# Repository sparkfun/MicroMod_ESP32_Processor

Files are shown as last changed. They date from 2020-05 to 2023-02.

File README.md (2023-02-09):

SparkFun MicroMod ESP32 Processor Board
========================================

SparkFun MicroMod ESP32 Processor Board (https://www.sparkfun.com/products/16781)

[*SparkFun MicroMod ESP32 Processor Board (16781)*](https://www.sparkfun.com/products/16781)

The MicroMod ESP32 Processor Board combines Espressif's ESP32 with our M.2 connector interface to bring a power-packed processor board into our MicroMod ecosystem. 

The ESP32 includes a laundry list of functionality, including the dual-core Tensilica LX6 microprocessor, 240MHz clock frequency, 520kB internal SRAM, integrated WiFi transceiver, and hardware accelerated encryption (AES, SHA2, ECC, RSA-4096). With this MicroMod processor board, you have access to 8 general use IO pins, dedicated analog, digital, and PWM pins, as well as all the fan favorites - SPI, I<sup>2</sup>C, UART, and SDIO. Add to that 16MB flash storage and sleep current of around 500&micro;A, and you've got a perfect storm of versatility. 

Grab yourself a SparkFun MicroMod ESP32 Processor Board and a compatible carrier board and get to hacking! 

Repository Contents
-------------------

* **/Documentation** - Data sheets, additional product information
* **/Hardware** - Eagle design files (.brd, .sch)
* **/Production** - Production panel files (.brd)

Documentation
--------------
* **[Hookup Guide](https://learn.sparkfun.com/tutorials/micromod-esp32-processor-board-hookup-guide)** - Basic hookup guide for the SparkFun MicroMod ESP32 Processor Board.
* **[Getting Started with MicroMod](https://learn.sparkfun.com/tutorials/getting-started-with-micromod)** - A tutorial to help you get started with the MicroMod Ecosystem. 
* **[Designing with MicroMod](https://learn.sparkfun.com/tutorials/designing-with-micromod)** - A tutorial to walk you through the specs of the MicroMod processor and carrier board as well as the basics of incorporating the MicroMod form factor into your own PCB designs.

License Information
-------------------

This product is _**open source**_! 

Please review the LICENSE.md file for license information. 

If you have any questions or concerns on licensing, please contact technical support on our [SparkFun forums](https://forum.sparkfun.com/viewforum.php?f=152).

Distributed as-is; no warranty is given.

- Your friends at SparkFun.

_<COLLABORATION CREDIT>_

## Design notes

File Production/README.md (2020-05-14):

SparkFun <PRODUCT NAME> Production Files
=========================================

These are the production files SparkFun uses for printing PCBs.

License Information
-------------------
This product is open source! 

The hardware is released under [Creative Commons ShareAlike 4.0 International](https://creativecommons.org/licenses/by-sa/4.0/).

Please use, reuse, and modify these files as you see fit. Please maintain attribution to SparkFun Electronics and release anything derivative under the same license.

Distributed as-is; no warranty is given.

- Your friends at SparkFun.

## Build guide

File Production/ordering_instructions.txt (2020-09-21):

panel size, 194x70mm
PCB thickness, 0.8mm
number of layers, 4
soldermask color, Red
silkscreen color, White
oz copper, 1oz
finish, ENIG
stencils, top+bottom
pcs per panel, 16
min trace width, 0.1270mm / 0.0050in
min drill size, 0.2000mm / 0.0079in
filename to layer stackup 1/2/3/4: GTL, GL2, GL3, GBL

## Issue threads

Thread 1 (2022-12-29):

ESP32 automatic reset into bootloader fails due to missing capacitor on RESET (EN) signal

cdwilson, 2022-12-29:
### Issue
I get an error message like the following when trying to program the MicroMod ESP32 Processor board with `esptool.py` using the automatic reset hardware built onto the board:

```
esptool.py v3.3
Serial port /dev/cu.usbserial-2130
Connecting......................................

A fatal error occurred: Failed to connect to Espressif device: Wrong boot mode detected (0x13)! The chip needs to be in download mode.
For troubleshooting steps visit: https://docs.espressif.com/projects/esptool/en/latest/troubleshooting.html
```

### Solution

I think the board is missing a capacitor between the `RESET#` signal (connected to ESP32 `CHIP_PU`/`EN`) and `GND`. This capacitor is required for the automatic reset circuit to work reliably.

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

See https://docs.espressif.com/projects/esptool/en/latest/esp32/advanced-topics/boot-mode-selection.html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, specifically:

> adding a capacitor between the EN pin and GND (in the 1uF-10uF range) is necessary for the reset circuitry to work reliably

### Rework

Here's some photos of the rework I did to get things working in case somebody comes across this issue in the future.

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

After adding a 1 uF capacitor between the `RESET#` signal and `GND`, programming via `esptool.py` works correctly:

```
esptool.py v3.3
Serial port /dev/cu.usbserial-2130
Connecting....
Detecting chip type... Unsupported detection protocol, switching and trying again...
Connecting....
Detecting chip type... ESP32
Chip is ESP32-D0WDQ6-V3 (revision 3)
Features: WiFi, BT, Dual Core, 240MHz, VRef calibration in efuse, Coding Scheme None
Crystal is 40MHz
MAC: 24:6f:28:8f:5d:bc
Uploading stub...
Running stub...
Stub running...
Changing baud rate to 921600
Changed.
Configuring flash size...
Auto-detected Flash size: 16MB
Flash will be erased from 0x00001000 to 0x00007fff...
Flash will be erased from 0x00008000 to 0x00008fff...
Flash will be erased from 0x00010000 to 0x00033fff...
Flash params set to 0x0240
Wrote 32768 bytes at 0x00001000 in 0.5 seconds (531.7 kbit/s)...
Hash of data verified.
Wrote 16384 bytes at 0x00008000 in 0.2 seconds (582.0 kbit/s)...
Hash of data verified.
Wrote 147456 bytes at 0x00010000 in 2.0 seconds (595.1 kbit/s)...
Hash of data verified.

Leaving...
Hard resetting via RTS pin...
```

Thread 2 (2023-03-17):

Hardware revision request: Improve power efficiency

adamgarbo, 2023-03-17:
Hi folks,

Unfortunately, the ESP32 MicroMod Process cannot achieve low quiescent draw when in deep sleep. I figured I'd throw this up on GitHub just in case the ESP32 ever sees a hardware revision.

Quoting @chEEm from the forums: https://forum.sparkfun.com/viewtopic.php?f=182&t=58183

> Unfortunately the CP210X USB to serial chip on the ESP32 module is connected to the 3.3V rail and not bus powered from 5V. The suspend pin is not utilized either which could reduce the quiescent current but is rather useless since the chip only needs to be active with a USB connection. A few traces need to be cut along with some jumper wires added to remove the VREGIN pin from 3.3V and add to V_USB power. It was relatively straight forward to do with a microscope and some 32 AWG wire. The bus powered configuration is shown in the typical connection diagram on page 18 of the CP210X datasheet ([https://www.silabs.com/documents/public ... 2102-9.pdf](https://www.silabs.com/documents/public/data-sheets/CP2102-9.pdf)). Afterwards my deep sleep 3.3V current dropped from 3mA to under 10uA.

At the very least, the product page should remove the stated 500 uA hibernation draw.

Cheers,
Adam

Closed 2024-09-25.

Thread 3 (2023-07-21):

Bootstrap pins on MicroMod connector can cause incompatibilities

shulltronics, 2023-07-21:
Hi there,

I'm one of the SPE design challenge participants, so I received a Single Pair Ethernet kit that includes this board. When I started to play with this kit, I realized that I couldn't flash the Esp32! This was my first time working with one, so I subsequently learned about the bootstrap pins, and then realized that GPIO12 on the Esp32 (broken out to PWM1 (pin 47?) on the MircoMod connector) was being pulled high by the SPE function board. See [my issue over there](https://github.com/sparkfun/SparkFun_MicroMod_Single_Pair_Ethernet_Function_Board_ADIN1110/issues/1) as well.

#### Work Around
I was able to burn the efuses on the Esp32 with `espefuse.py set_flash_voltage 3.3V` to hard-code the MCU's internal flash to 3.3V.

#### Possible Solutions
While the work around seems to allow the boards to work together, it doesn't seem like the ideal solution, as it requires some specialized knowledge to get to that solution, and is an irreversible action. The only way I could see this being feasible is if Sparkfun did the fuse setting before shipping these boards to customers. The most robust solution, though maybe too limiting, is to remove the bootstrap pins from the MicroMod connector entirely. This would prevent any incompatibilities with future function boards.

Anyway, I would love to hear your thoughts on this! :) Thanks!

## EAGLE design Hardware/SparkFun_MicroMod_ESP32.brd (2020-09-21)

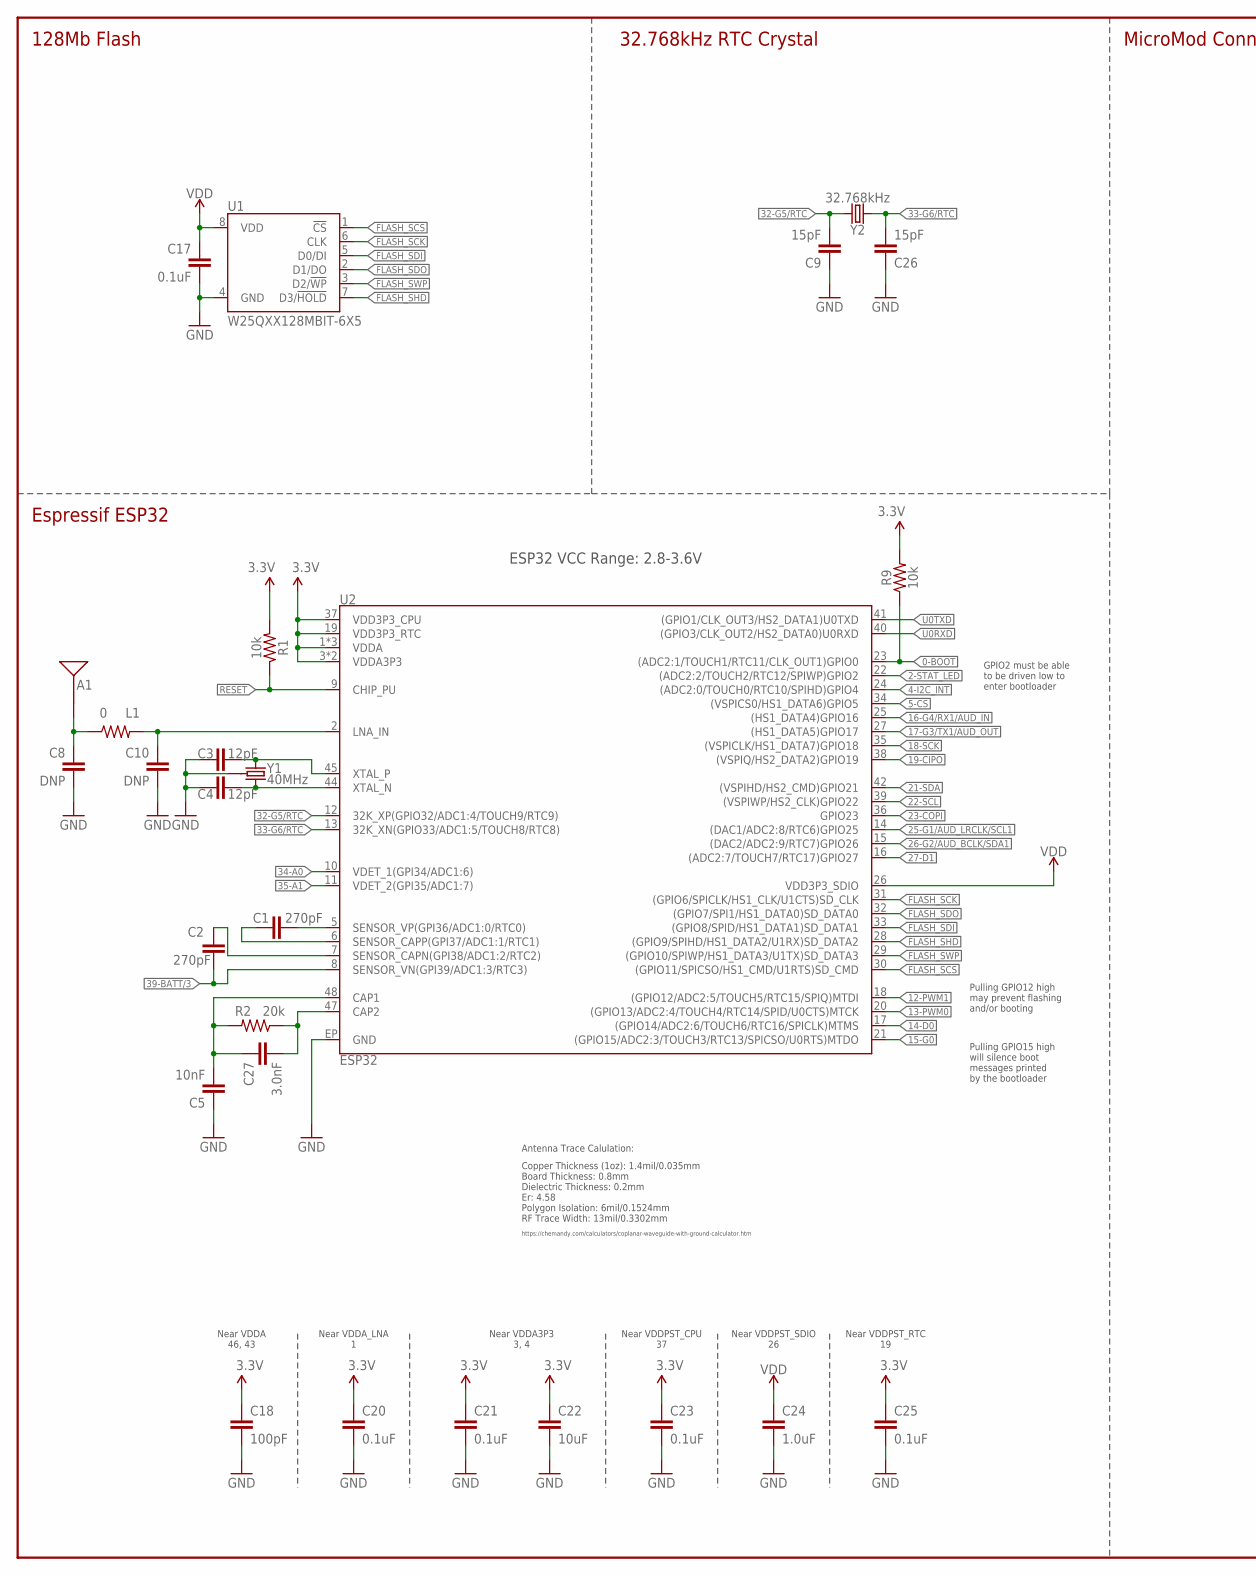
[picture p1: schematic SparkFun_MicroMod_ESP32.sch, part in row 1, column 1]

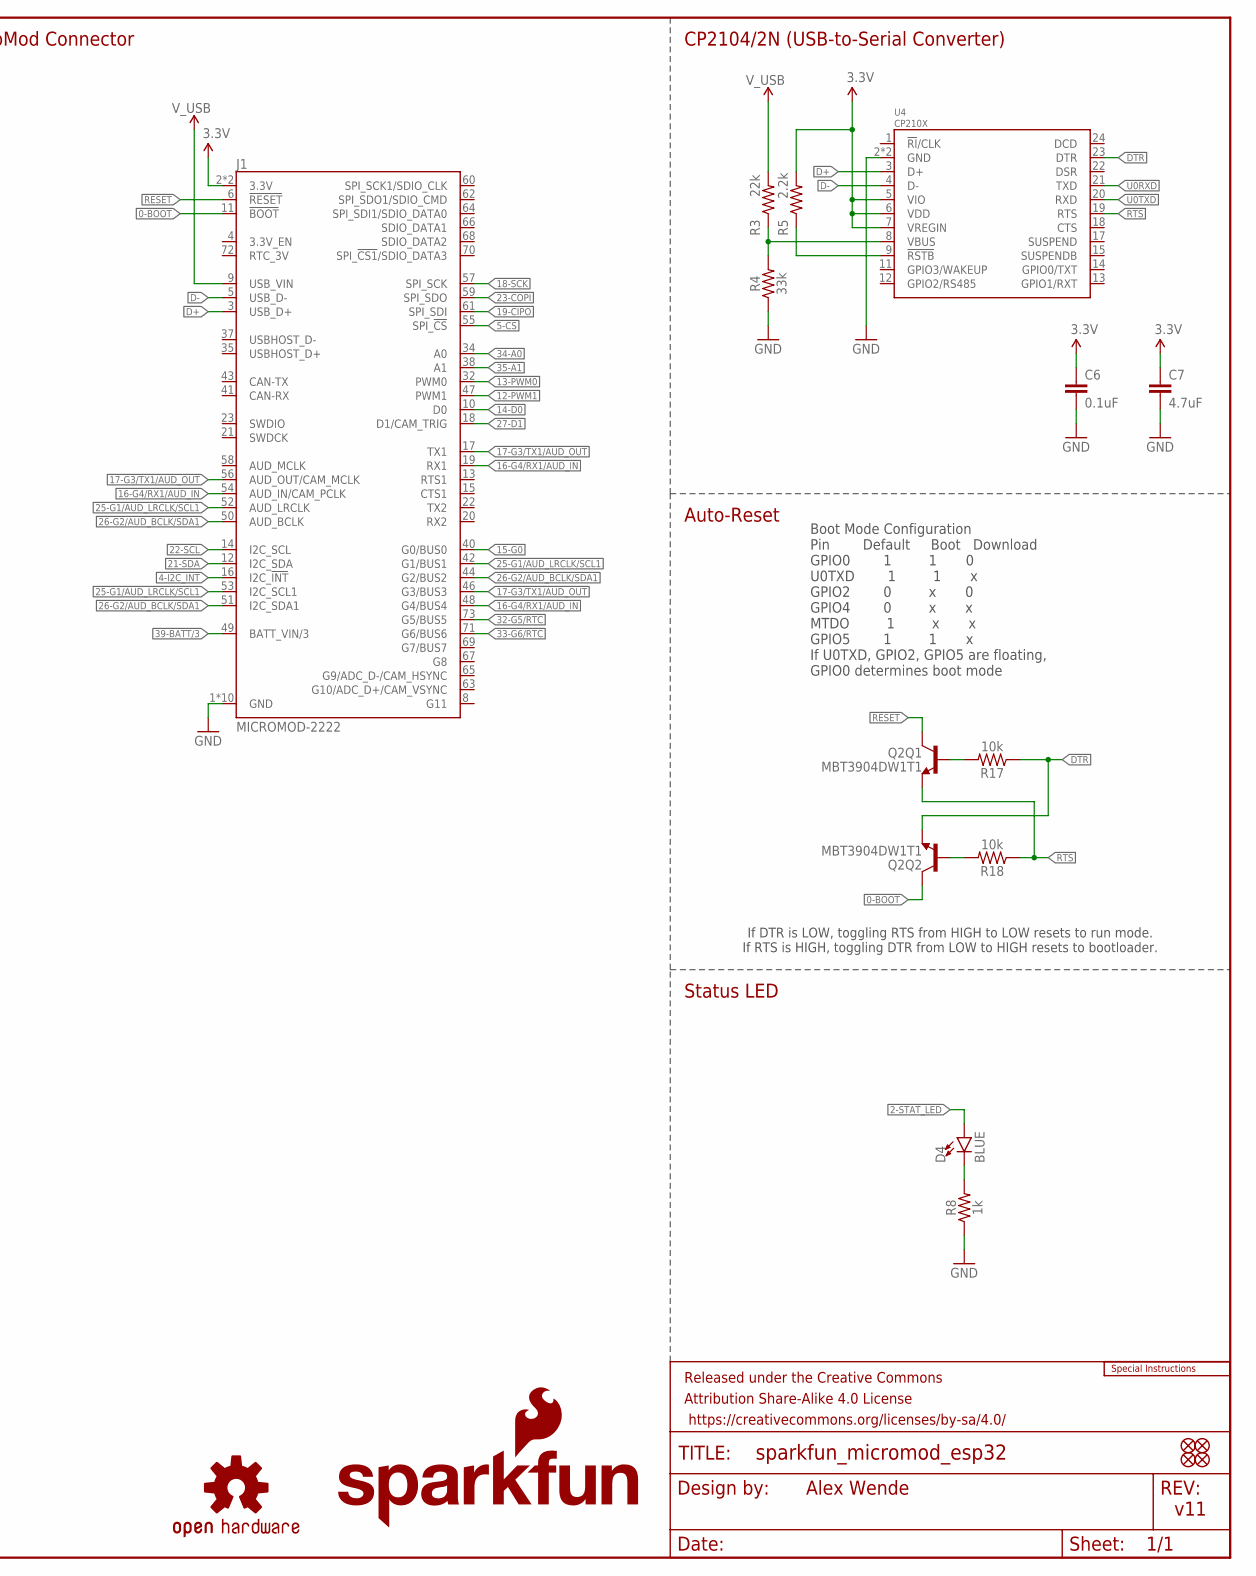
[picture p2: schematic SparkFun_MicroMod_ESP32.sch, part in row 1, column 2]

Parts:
A1: ANTENNA2.4GHZ-8.0X1.0MM; ANT-2.4GHZ-8.0X1.0MM
C1, C2: 270pF; 0402-TIGHT
C3, C4: 12pF; 0402-TIGHT
C5: 10nF; 0402-TIGHT
C6, C17, C20, C21, C23, C25: 0.1uF; 0402-TIGHT
C7: 4.7uF; 0402-TIGHT
C8, C10: DNP; 0402-TIGHT
C9, C26: 15pF; 0402-TIGHT
C18: 100pF; 0402-TIGHT
C22: 10uF; 0402-TIGHT
C24: 1.0uF; 0402-TIGHT
C27: 3.0nF; 0402-TIGHT
D4: BLUE; LED-0603
FD1, FD2, FD3, FD4: FIDUCIALUFIDUCIAL; FIDUCIAL-MICRO
FRAME1: FRAME-LEDGER; CREATIVE_COMMONS
J1: MICROMOD-2222; M.2-CARD-E-22
L1: 0; 0402-TIGHT
LOGO1: SPECIAL_INSTRUCTIONS-ORDERING; ORDERING_INSTRUCTIONS
LOGO2: SFE_LOGO_NAME_FLAME.1_INCH; SFE_LOGO_NAME_FLAME_.1
LOGO3: OSHW-LOGOS; OSHW-LOGO-S
Q2: MBT3904DW1T1; SC70-6
R1, R9, R17, R18: 10k; 0402-TIGHT
R2: 20k; 0402-TIGHT
R3: 22k; 0402-TIGHT
R4: 33k; 0402-TIGHT
R5: 2.2k; 0402-TIGHT
R8: 1k; 0402-TIGHT
U1: W25QXX128MBIT-6X5; WSON-8-6X5
U2: ESP32; QFN48-0.4MM
U4: CP210X; QFN24
Y1: 40MHz; CRYSTAL-SMD-2X2.5MM
Y2: 32.768kHz; CRYSTAL-SMD-3.2X1.5MM

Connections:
0-!BOOT!: J1.11 (!BOOT!), Q2.6 (C), R9.1, U2.23 ((ADC2:1/TOUCH1/RTC11/CLK_OUT1)GPIO0)
2-STAT_LED: D4.A, U2.22 ((ADC2:2/TOUCH2/RTC12/SPIWP)GPIO2)
3.3V: C6.1, C7.1, C18.1, C20.1, C21.1, C22.1, C23.1, C25.1, J1.2 (3.3V), J1.74 (3.3V), R1.2, R5.2, R9.2, U2.1 (VDDA), U2.3 (VDDA3P3), U2.4 (VDDA3P3), U2.19 (VDD3P3_RTC), U2.37 (VDD3P3_CPU), U2.43 (VDDA), U2.46 (VDDA), U4.5 (VIO), U4.6 (VDD), U4.7 (VREGIN)
4-I2C_!INT: J1.16 (I2C_!INT!), U2.24 ((ADC2:0/TOUCH0/RTC10/SPIHD)GPIO4)
5-!CS: J1.55 (SPI_!CS!), U2.34 ((VSPICS0/HS1_DATA6)GPIO5)
12-PWM1: J1.47 (PWM1), U2.18 ((GPIO12/ADC2:5/TOUCH5/RTC15/SPIQ)MTDI)
13-PWM0: J1.32 (PWM0), U2.20 ((GPIO13/ADC2:4/TOUCH4/RTC14/SPID/U0CTS)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)
14-D0: J1.10 (D0), U2.17 ((GPIO14/ADC2:6/TOUCH6/RTC16/SPICLK)MTMS)
15-G0: J1.40 (G0/BUS0), U2.21 ((GPIO15/ADC2:3/TOUCH3/RTC13/SPICSO/U0RT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)
16-G4/RX1/AUD_IN: J1.19 (RX1), J1.48 (G4/BUS4), J1.54 (AUD_IN/CAM_PCLK), U2.25 ((HS1_DATA4)GPIO16)
17-G3/TX1/AUD_OUT: J1.17 (TX1), J1.46 (G3/BUS3), J1.56 (AUD_OUT/CAM_MCLK), U2.27 ((HS1_DATA5)GPIO17)
18-SCK: J1.57 (SPI_SCK), U2.35 ((VSPICLK/HS1_DATA7)GPIO18)
19-CIPO: J1.61 (SPI_SDI), U2.38 ((VSPIQ/HS2_DATA2)GPIO19)
21-SDA: J1.12 (I2C_SDA), U2.42 ((VSPIHD/HS2_CMD)GPIO21)
22-SCL: J1.14 (I2C_SCL), U2.39 ((VSPIWP/HS2_CLK)GPIO22)
23-COPI: J1.59 (SPI_SDO), U2.36 (GPIO23)
25-G1/AUD_LRCLK/SCL1: J1.42 (G1/BUS1), J1.52 (AUD_LRCLK), J1.53 (I2C_SCL1), U2.14 ((DAC1/ADC2:8/RTC6)GPIO25)
26-G2/AUD_BCLK/SDA1: J1.44 (G2/BUS2), J1.50 (AUD_BCLK), J1.51 (I2C_SDA1), U2.15 ((DAC2/ADC2:9/RTC7)GPIO26)
27-D1: J1.18 (D1/CAM_TRIG), U2.16 ((ADC2:7/TOUCH7/RTC17)GPIO27)
32-G5/RTC: C9.2, J1.73 (G5/BUS5), U2.12 (32K_XP(GPIO32/ADC1:4/TOUCH9/RTC9)), Y2.P$1 (1)
33-G6/RTC: C26.2, J1.71 (G6/BUS6), U2.13 (32K_XN(GPIO33/ADC1:5/TOUCH8/RTC8)), Y2.P$2 (2)
34-A0: J1.34 (A0), U2.10 (VDET_1(GPI34/ADC1:6))
35-A1: J1.38 (A1), U2.11 (VDET_2(GPI35/ADC1:7))
36: C1.2, U2.5 (SENSOR_VP(GPI36/ADC1:0/RTC0))
37: C1.1, U2.6 (SENSOR_CAPP(GPI37/ADC1:1/RTC1))
38: C2.1, U2.7 (SENSOR_CAPN(GPI38/ADC1:2/RTC2))
39-BATT/3: C2.2, J1.49 (BATT_VIN/3), U2.8 (SENSOR_VN(GPI39/ADC1:3/RTC3))
!RESET: J1.6 (!RESET!), Q2.3 (C), R1.1, U2.9 (CHIP_PU)
CAP_10N: C5.2, C27.1, R2.2, U2.48 (CAP1)
D+: J1.3 (USB_D+), U4.3 (D+)
D-: J1.5 (USB_D-), U4.4 (D-)
DTR: Q2.1 (E), R17.1, U4.23 (DTR)
FLASH_SCK: U1.6 (CLK), U2.31 ((GPIO6/SPICLK/HS1_CLK/U1CTS)SD_CLK)
FLASH_SCS: U1.1 (!CS!), U2.30 ((GPIO11/SPICSO/HS1_CMD/U1RTS)SD_CMD)
FLASH_SDI: U1.5 (D0/DI), U2.33 ((GPIO8/SPID/HS1_DATA1)SD_DATA1)
FLASH_SDO: U1.2 (D1/DO), U2.32 ((GPIO7/SPI1/HS1_DATA0)SD_DATA0)
FLASH_SHD: U1.7 (D3/!HOLD!), U2.28 ((GPIO9/SPIHD/HS1_DATA2/U1RX)SD_DATA2)
FLASH_SWP: U1.3 (D2/!WP!), U2.29 ((GPIO10/SPIWP/HS1_DATA3/U1TX)SD_DATA3)
GND: C3.1, C4.1, C5.1, C6.2, C7.2, C8.2, C9.1, C10.2, C17.2, C18.2, C20.2, C21.2, C22.2, C23.2, C24.2, C25.2, C26.1, J1.1 (GND), J1.7 (GND), J1.33 (GND), J1.36 (GND), J1.39 (GND), J1.45 (GND), J1.75 (GND), J1.GND1 (GND), J1.GND2 (GND), J1.GND3 (GND), R4.1, R8.1, U1.4 (GND), U2.EP (GND), U4.2 (GND), U4.PAD (GND), Y1.P2 (GND), Y1.P4 (GND)
unnamed: D4.C, R8.2
unnamed: R3.1, R4.2, U4.8 (VBUS)
unnamed: R5.1, U4.9 (!RSTB)
unnamed: C27.2, R2.1, U2.47 (CAP2)
unnamed: A1.FEED, C8.1, L1.1
unnamed: C10.1, L1.2, U2.2 (LNA_IN)
unnamed: Q2.5 (B), R17.2
unnamed: Q2.2 (B), R18.2
unnamed: C3.2, U2.45 (XTAL_P), Y1.P1 (1)
unnamed: C4.2, U2.44 (XTAL_N), Y1.P3 (2)
RTS: Q2.4 (E), R18.1, U4.19 (RTS)
U0RXD: U2.40 ((GPIO3/CLK_OUT2/HS2_DATA0)U0RXD), U4.21 (TXD)
U0TXD: U2.41 ((GPIO1/CLK_OUT3/HS2_DATA1)U0TXD), U4.20 (RXD)
VDD: C17.1, C24.1, U1.8 (VDD), U2.26 (VDD3P3_SDIO)
V_USB: J1.9 (USB_VIN), R3.2

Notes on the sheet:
Boot Mode Configuration Pin Default Boot Download GPIO0 1 1 0 U0TXD 1 1 x GPIO2 0 x 0 GPIO4 0 x x MTDO 1 x x GPIO5 1 1 x If U0TXD, GPIO2, GPIO5 are floating, GPIO0 determines boot mode
Auto-Reset
Near VDDA 46, 43
Near VDDA_LNA 1
Near VDDA3P3 3, 4
Near VDDPST_CPU 37
Near VDDPST_SDIO 26
Near VDDPST_RTC 19
Espressif ESP32
128Mb Flash
32.768kHz RTC Crystal
Status LED
v11
Alex Wende
ESP32 VCC Range: 2.8-3.6V
If DTR is LOW, toggling RTS from HIGH to LOW resets to run mode. If RTS is HIGH, toggling DTR from LOW to HIGH resets to bootloader.
CP2104/2N (USB-to-Serial Converter)
MicroMod Connector
Antenna Trace Calulation:
Copper Thickness (1oz): 1.4mil/0.035mm Board Thickness: 0.8mm Dielectric Thickness: 0.2mm Er: 4.58 Polygon Isolation: 6mil/0.1524mm RF Trace Width: 13mil/0.3302mm
https://chemandy.com/calculators/coplanar-waveguide-with-ground-calculator.htm
GPIO2 must be able to be driven low to enter bootloader
Pulling GPIO12 high may prevent flashing and/or booting
Pulling GPIO15 high will silence boot messages printed by the bootloader

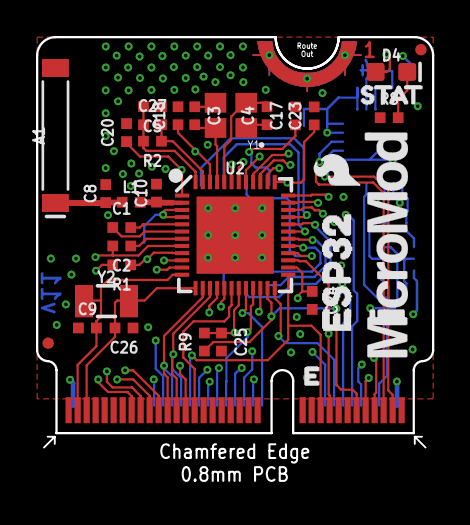
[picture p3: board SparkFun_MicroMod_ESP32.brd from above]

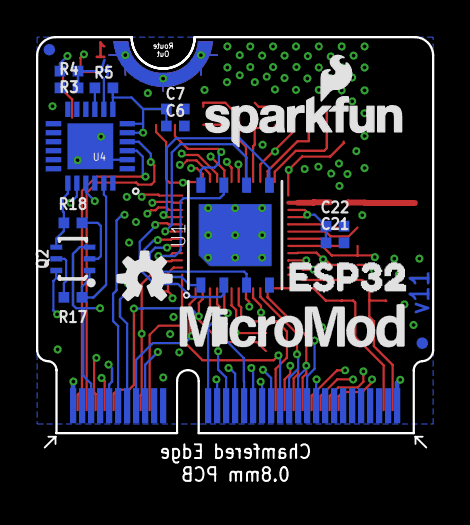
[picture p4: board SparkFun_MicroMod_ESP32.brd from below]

Board: 4 copper layers, 22.0 x 22.8 mm, 53 parts (18 on the bottom side), 54 nets.

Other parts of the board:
U$1: STAT0
U$2, U$6: MICROMOD_LOGO_.5
U$3, U$7: ESP321
U$4: SFE_LOGO_FLAME_.1

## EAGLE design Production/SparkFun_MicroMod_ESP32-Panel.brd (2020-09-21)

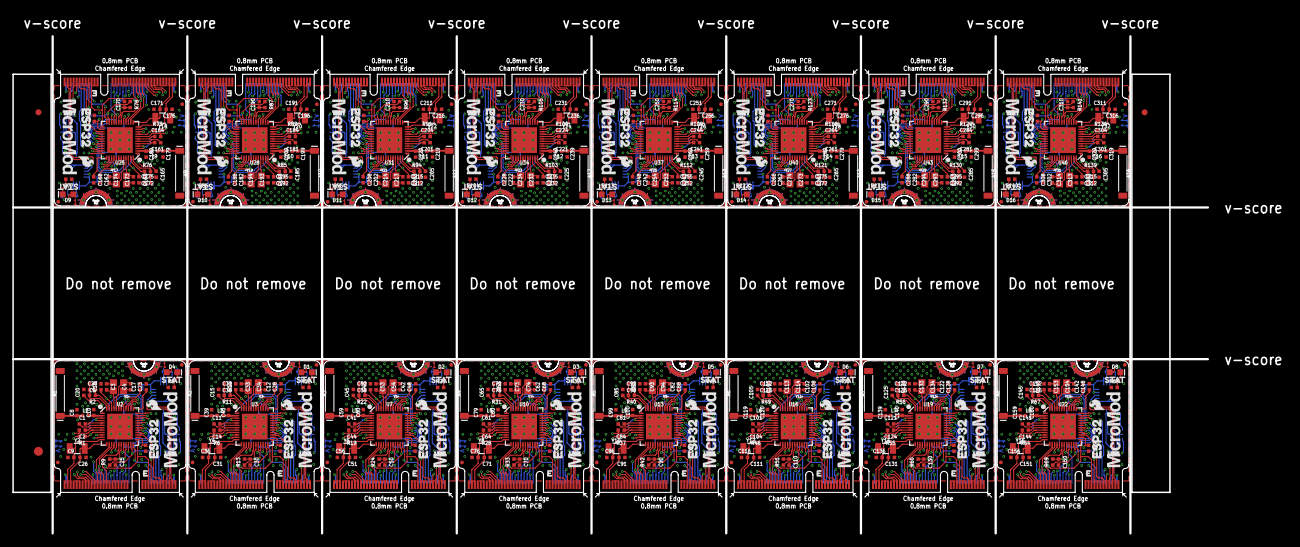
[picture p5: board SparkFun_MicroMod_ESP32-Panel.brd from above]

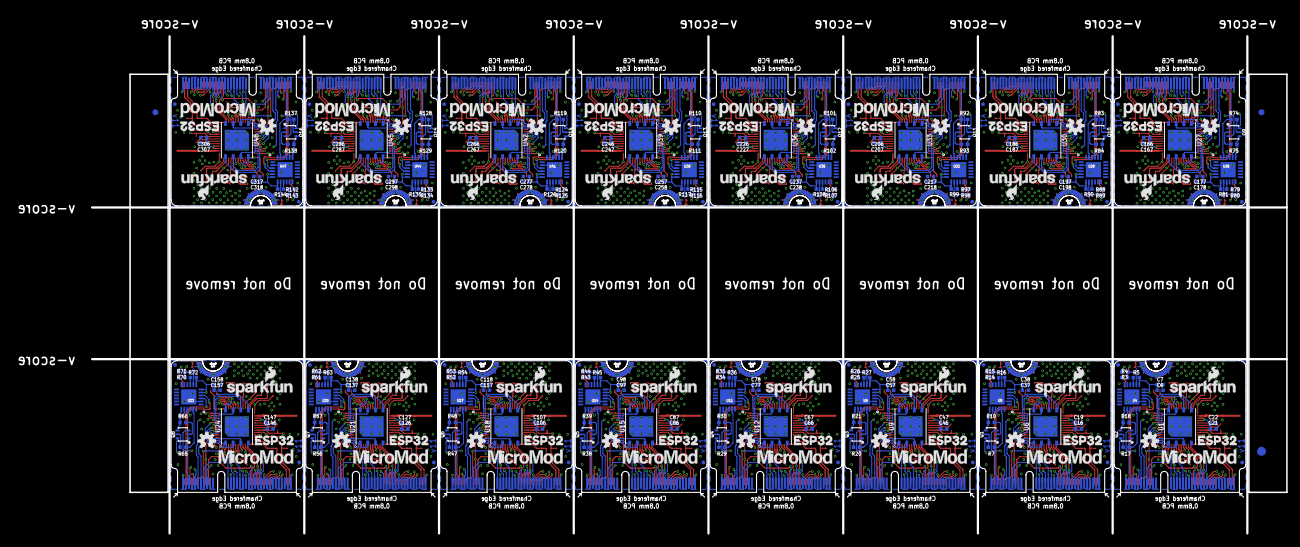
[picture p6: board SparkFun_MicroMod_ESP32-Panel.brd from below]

Board: 4 copper layers, 199.6 x 83.1 mm, 822 parts (291 on the bottom side), 864 nets.

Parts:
A1, A2, A3, A4, A5, A6, A7, A8, A9, A10, A11, A12, A13, A14, A15, A16: ANT-2.4GHZ-8.0X1.0MM
C1, C2, C11, C14, C41, C44, C61, C64, C81, C84, C101, C104, C121, C124, C141, C144, C161, C164, C181, C184, C201, C204, C221, C224, C241, C244, C261, C264, C281, C284, C301, C304: 270pF; 0402-TIGHT
C3, C4, C33, C34, C53, C54, C73, C74, C93, C94, C113, C114, C133, C134, C153, C154, C173, C174, C193, C194, C213, C214, C233, C234, C253, C254, C273, C274, C293, C294, C313, C314: 12pF; 0402-TIGHT
C5, C35, C55, C75, C95, C115, C135, C155, C175, C195, C215, C235, C255, C275, C295, C315: 10nF; 0402-TIGHT
C6, C12, C15, C16, C17, C20, C21, C23, C25, C28, C30, C37, C42, C45, C46, C48, C50, C57, C62, C65, C66, C68, C70, C77, C82, C85, C86, C88, C90, C97, C102, C105, C106, C108, C110, C117, C122, C125, C126, C128, C130, C137, C142, C145, C146, C148, C150, C157, C162, C165, C166, C168, C170, C177, C182, C185, C186, C188, C190, C197, C202, C205, C206, C208, C210, C217, C222, C225, C226, C228, C230, C237, C242, C245, C246, C248, C250, C257, C262, C265, C266, C268, C270, C277, C282, C285, C286, C288, C290, C297, C302, C305, C306, C308, C310, C317: 0.1uF; 0402-TIGHT
C7, C38, C58, C78, C98, C118, C138, C158, C178, C198, C218, C238, C258, C278, C298, C318: 4.7uF; 0402-TIGHT
C8, C10, C39, C40, C59, C60, C79, C80, C99, C100, C119, C120, C139, C140, C159, C160, C179, C180, C199, C200, C219, C220, C239, C240, C259, C260, C279, C280, C299, C300, C319, C320: DNP; 0402-TIGHT
C9, C26, C31, C36, C51, C56, C71, C76, C91, C96, C111, C116, C131, C136, C151, C156, C171, C176, C191, C196, C211, C216, C231, C236, C251, C256, C271, C276, C291, C296, C311, C316: 15pF; 0402-TIGHT
C13, C18, C43, C63, C83, C103, C123, C143, C163, C183, C203, C223, C243, C263, C283, C303: 100pF; 0402-TIGHT
C19, C22, C47, C67, C87, C107, C127, C147, C167, C187, C207, C227, C247, C267, C287, C307: 10uF; 0402-TIGHT
C24, C29, C49, C69, C89, C109, C129, C149, C169, C189, C209, C229, C249, C269, C289, C309: 1.0uF; 0402-TIGHT
C27, C32, C52, C72, C92, C112, C132, C152, C172, C192, C212, C232, C252, C272, C292, C312: 3.0nF; 0402-TIGHT
D1, D2, D3, D4, D5, D6, D7, D8, D9, D10, D11, D12, D13, D14, D15, D16: BLUE; LED-0603
E$1, E$2, E$3, E$4: FIDUCIAL-1X2
E$5, E$6: FIDUCIAL-1.5X3
FD1, FD2, FD3, FD4, FD5, FD6, FD7, FD8, FD9, FD10, FD11, FD12, FD13, FD14, FD15, FD16, FD17, FD18, FD19, FD20, FD21, FD22, FD23, FD24, FD25, FD26, FD27, FD28, FD29, FD30, FD31, FD32, FD33, FD34, FD35, FD36, FD37, FD38, FD39, FD40, FD41, FD42, FD43, FD44, FD45, FD46, FD47, FD48, FD49, FD50, FD51, FD52, FD53, FD54, FD55, FD56, FD57, FD58, FD59, FD60, FD61, FD62, FD63, FD64: FIDUCIALUFIDUCIAL; FIDUCIAL-MICRO
J1, J2, J3, J4, J5, J6, J7, J8, J9, J10, J11, J12, J13, J14, J15, J16: MICROMOD-2222; M.2-CARD-E-22
L1, L2, L3, L4, L5, L6, L7, L8, L9, L10, L11, L12, L13, L14, L15, L16: 0; 0402-TIGHT
LOGO1, LOGO2, LOGO5, LOGO7, LOGO9, LOGO11, LOGO13, LOGO15, LOGO17, LOGO19, LOGO21, LOGO23, LOGO25, LOGO27, LOGO29, LOGO31: SFE_LOGO_NAME_FLAME.1_INCH; SFE_LOGO_NAME_FLAME_.1
LOGO3, LOGO4, LOGO6, LOGO8, LOGO10, LOGO12, LOGO14, LOGO16, LOGO18, LOGO20, LOGO22, LOGO24, LOGO26, LOGO28, LOGO30, LOGO32: OSHW-LOGOS; OSHW-LOGO-S
Q1, Q2, Q3, Q4, Q5, Q6, Q7, Q8, Q9, Q10, Q11, Q12, Q13, Q14, Q15, Q16: MBT3904DW1T1; SC70-6
R1, R6, R7, R9, R10, R13, R17, R18, R19, R20, R21, R24, R28, R29, R30, R33, R37, R38, R39, R42, R46, R47, R48, R51, R55, R56, R57, R60, R64, R65, R66, R69, R73, R74, R75, R78, R82, R83, R84, R87, R91, R92, R93, R96, R100, R101, R102, R105, R109, R110, R111, R114, R118, R119, R120, R123, R127, R128, R129, R132, R136, R137, R138, R141: 10k; 0402-TIGHT
R2, R11, R22, R31, R40, R49, R58, R67, R76, R85, R94, R103, R112, R121, R130, R139: 20k; 0402-TIGHT
R3, R14, R25, R34, R43, R52, R61, R70, R79, R88, R97, R106, R115, R124, R133, R142: 22k; 0402-TIGHT
R4, R15, R26, R35, R44, R53, R62, R71, R80, R89, R98, R107, R116, R125, R134, R143: 33k; 0402-TIGHT
R5, R16, R27, R36, R45, R54, R63, R72, R81, R90, R99, R108, R117, R126, R135, R144: 2.2k; 0402-TIGHT
R8, R12, R23, R32, R41, R50, R59, R68, R77, R86, R95, R104, R113, R122, R131, R140: 1k; 0402-TIGHT
U1, U6, U9, U12, U15, U18, U21, U24, U27, U30, U33, U36, U39, U42, U45, U48: W25QXX128MBIT-6X5; WSON-8-6X5
U2, U3, U7, U10, U13, U16, U19, U22, U25, U28, U31, U34, U37, U40, U43, U46: ESP32; QFN48-0.4MM
U4, U5, U8, U11, U14, U17, U20, U23, U26, U29, U32, U35, U38, U41, U44, U47: CP210X; QFN24
U$1, U$5, U$13, U$19, U$25, U$31, U$37, U$43, U$49, U$55, U$61, U$67, U$73, U$79, U$85, U$91: STAT0
U$2, U$6, U$9, U$11, U$15, U$17, U$21, U$23, U$27, U$29, U$33, U$35, U$39, U$41, U$45, U$47, U$51, U$53, U$57, U$59, U$63, U$65, U$69, U$71, U$75, U$77, U$81, U$83, U$87, U$89, U$93, U$95: MICROMOD_LOGO_.5
U$3, U$7, U$8, U$12, U$14, U$18, U$20, U$24, U$26, U$30, U$32, U$36, U$38, U$42, U$44, U$48, U$50, U$54, U$56, U$60, U$62, U$66, U$68, U$72, U$74, U$78, U$80, U$84, U$86, U$90, U$92, U$96: ESP321
U$4, U$10, U$16, U$22, U$28, U$34, U$40, U$46, U$52, U$58, U$64, U$70, U$76, U$82, U$88, U$94: SFE_LOGO_FLAME_.1
Y1, Y3, Y5, Y7, Y9, Y11, Y13, Y15, Y17, Y19, Y21, Y23, Y25, Y27, Y29, Y31: 40MHz; CRYSTAL-SMD-2X2.5MM
Y2, Y4, Y6, Y8, Y10, Y12, Y14, Y16, Y18, Y20, Y22, Y24, Y26, Y28, Y30, Y32: 32.768kHz; CRYSTAL-SMD-3.2X1.5MM

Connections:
0-!BOOT!: J1.11, Q2.6, R9.1, U2.23
0-!BOOT!1: J2.11, Q1.6, R13.1, U3.23
0-!BOOT!2: J3.11, Q3.6, R24.1, U7.23
0-!BOOT!3: J4.11, Q4.6, R33.1, U10.23
0-!BOOT!4: J5.11, Q5.6, R42.1, U13.23
0-!BOOT!5: J6.11, Q6.6, R51.1, U16.23
0-!BOOT!6: J7.11, Q7.6, R60.1, U19.23
0-!BOOT!7: J8.11, Q8.6, R69.1, U22.23
0-!BOOT!8: J9.11, Q9.6, R78.1, U25.23
0-!BOOT!9: J10.11, Q10.6, R87.1, U28.23
0-!BOOT!10: J11.11, Q11.6, R96.1, U31.23
0-!BOOT!11: J12.11, Q12.6, R105.1, U34.23
0-!BOOT!12: J13.11, Q13.6, R114.1, U37.23
0-!BOOT!13: J14.11, Q14.6, R123.1, U40.23
0-!BOOT!14: J15.11, Q15.6, R132.1, U43.23
0-!BOOT!15: J16.11, Q16.6, R141.1, U46.23
1: C14.1, U3.7
2: C11.2, U3.5
2-STAT_LED: D4.A, U2.22
2-STAT_LED1: D1.A, U3.22
2-STAT_LED2: D2.A, U7.22
2-STAT_LED3: D3.A, U10.22
2-STAT_LED4: D5.A, U13.22
2-STAT_LED5: D6.A, U16.22
2-STAT_LED6: D7.A, U19.22
2-STAT_LED7: D8.A, U22.22
2-STAT_LED8: D9.A, U25.22
2-STAT_LED9: D10.A, U28.22
2-STAT_LED10: D11.A, U31.22
2-STAT_LED11: D12.A, U34.22
2-STAT_LED12: D13.A, U37.22
2-STAT_LED13: D14.A, U40.22
2-STAT_LED14: D15.A, U43.22
2-STAT_LED15: D16.A, U46.22
3: C11.1, U3.6
3.3V: C6.1, C7.1, C18.1, C20.1, C21.1, C22.1, C23.1, C25.1, J1.2, J1.74, R1.2, R5.2, R9.2, U2.1, U2.3, U2.4, U2.19, U2.37, U2.43, U2.46, U4.5, U4.6, U4.7
3.3V1: C13.1, C15.1, C16.1, C19.1, C28.1, C30.1, C37.1, C38.1, J2.2, J2.74, R6.2, R13.2, R16.2, U3.1, U3.3, U3.4, U3.19, U3.37, U3.43, U3.46, U5.5, U5.6, U5.7
3.3V2: C43.1, C45.1, C46.1, C47.1, C48.1, C50.1, C57.1, C58.1, J3.2, J3.74, R19.2, R24.2, R27.2, U7.1, U7.3, U7.4, U7.19, U7.37, U7.43, U7.46, U8.5, U8.6, U8.7
3.3V3: C63.1, C65.1, C66.1, C67.1, C68.1, C70.1, C77.1, C78.1, J4.2, J4.74, R28.2, R33.2, R36.2, U10.1, U10.3, U10.4, U10.19, U10.37, U10.43, U10.46, U11.5, U11.6, U11.7
3.3V4: C83.1, C85.1, C86.1, C87.1, C88.1, C90.1, C97.1, C98.1, J5.2, J5.74, R37.2, R42.2, R45.2, U13.1, U13.3, U13.4, U13.19, U13.37, U13.43, U13.46, U14.5, U14.6, U14.7
3.3V5: C103.1, C105.1, C106.1, C107.1, C108.1, C110.1, C117.1, C118.1, J6.2, J6.74, R46.2, R51.2, R54.2, U16.1, U16.3, U16.4, U16.19, U16.37, U16.43, U16.46, U17.5, U17.6, U17.7
3.3V6: C123.1, C125.1, C126.1, C127.1, C128.1, C130.1, C137.1, C138.1, J7.2, J7.74, R55.2, R60.2, R63.2, U19.1, U19.3, U19.4, U19.19, U19.37, U19.43, U19.46, U20.5, U20.6, U20.7
3.3V7: C143.1, C145.1, C146.1, C147.1, C148.1, C150.1, C157.1, C158.1, J8.2, J8.74, R64.2, R69.2, R72.2, U22.1, U22.3, U22.4, U22.19, U22.37, U22.43, U22.46, U23.5, U23.6, U23.7
3.3V8: C163.1, C165.1, C166.1, C167.1, C168.1, C170.1, C177.1, C178.1, J9.2, J9.74, R73.2, R78.2, R81.2, U25.1, U25.3, U25.4, U25.19, U25.37, U25.43, U25.46, U26.5, U26.6, U26.7
3.3V9: C183.1, C185.1, C186.1, C187.1, C188.1, C190.1, C197.1, C198.1, J10.2, J10.74, R82.2, R87.2, R90.2, U28.1, U28.3, U28.4, U28.19, U28.37, U28.43, U28.46, U29.5, U29.6, U29.7
3.3V10: C203.1, C205.1, C206.1, C207.1, C208.1, C210.1, C217.1, C218.1, J11.2, J11.74, R91.2, R96.2, R99.2, U31.1, U31.3, U31.4, U31.19, U31.37, U31.43, U31.46, U32.5, U32.6, U32.7
3.3V11: C223.1, C225.1, C226.1, C227.1, C228.1, C230.1, C237.1, C238.1, J12.2, J12.74, R100.2, R105.2, R108.2, U34.1, U34.3, U34.4, U34.19, U34.37, U34.43, U34.46, U35.5, U35.6, U35.7
3.3V12: C243.1, C245.1, C246.1, C247.1, C248.1, C250.1, C257.1, C258.1, J13.2, J13.74, R109.2, R114.2, R117.2, U37.1, U37.3, U37.4, U37.19, U37.37, U37.43, U37.46, U38.5, U38.6, U38.7
3.3V13: C263.1, C265.1, C266.1, C267.1, C268.1, C270.1, C277.1, C278.1, J14.2, J14.74, R118.2, R123.2, R126.2, U40.1, U40.3, U40.4, U40.19, U40.37, U40.43, U40.46, U41.5, U41.6, U41.7
3.3V14: C283.1, C285.1, C286.1, C287.1, C288.1, C290.1, C297.1, C298.1, J15.2, J15.74, R127.2, R132.2, R135.2, U43.1, U43.3, U43.4, U43.19, U43.37, U43.43, U43.46, U44.5, U44.6, U44.7
3.3V15: C303.1, C305.1, C306.1, C307.1, C308.1, C310.1, C317.1, C318.1, J16.2, J16.74, R136.2, R141.2, R144.2, U46.1, U46.3, U46.4, U46.19, U46.37, U46.43, U46.46, U47.5, U47.6, U47.7
4: C44.1, U7.7
4-I2C_!INT: J1.16, U2.24
4-I2C_!INT1: J2.16, U3.24
4-I2C_!INT2: J3.16, U7.24
4-I2C_!INT3: J4.16, U10.24
4-I2C_!INT4: J5.16, U13.24
4-I2C_!INT5: J6.16, U16.24
4-I2C_!INT6: J7.16, U19.24
4-I2C_!INT7: J8.16, U22.24
4-I2C_!INT8: J9.16, U25.24
4-I2C_!INT9: J10.16, U28.24
4-I2C_!INT10: J11.16, U31.24
4-I2C_!INT11: J12.16, U34.24
4-I2C_!INT12: J13.16, U37.24
4-I2C_!INT13: J14.16, U40.24
4-I2C_!INT14: J15.16, U43.24
4-I2C_!INT15: J16.16, U46.24
5: C41.2, U7.5
5-!CS: J1.55, U2.34
5-!CS1: J2.55, U3.34
5-!CS2: J3.55, U7.34
5-!CS3: J4.55, U10.34
5-!CS4: J5.55, U13.34
5-!CS5: J6.55, U16.34
5-!CS6: J7.55, U19.34
5-!CS7: J8.55, U22.34
5-!CS8: J9.55, U25.34
5-!CS9: J10.55, U28.34
5-!CS10: J11.55, U31.34
5-!CS11: J12.55, U34.34
5-!CS12: J13.55, U37.34
5-!CS13: J14.55, U40.34
5-!CS14: J15.55, U43.34
5-!CS15: J16.55, U46.34
6: C41.1, U7.6
7: C64.1, U10.7
8: C61.2, U10.5
9: C61.1, U10.6
10: C84.1, U13.7
11: C81.2, U13.5
12: C81.1, U13.6
12-PWM1: J1.47, U2.18
12-PWM2: J2.47, U3.18
12-PWM3: J3.47, U7.18
12-PWM4: J4.47, U10.18
12-PWM5: J5.47, U13.18
12-PWM6: J6.47, U16.18
12-PWM7: J7.47, U19.18
12-PWM8: J8.47, U22.18
12-PWM9: J9.47, U25.18
12-PWM10: J10.47, U28.18
12-PWM11: J11.47, U31.18
12-PWM12: J12.47, U34.18
12-PWM13: J13.47, U37.18
12-PWM14: J14.47, U40.18
12-PWM15: J15.47, U43.18
12-PWM16: J16.47, U46.18
13: C104.1, U16.7
13-PWM0: J1.32, U2.20
13-PWM1: J2.32, U3.20
13-PWM2: J3.32, U7.20
13-PWM3: J4.32, U10.20
13-PWM4: J5.32, U13.20
13-PWM5: J6.32, U16.20
13-PWM6: J7.32, U19.20
13-PWM7: J8.32, U22.20
13-PWM8: J9.32, U25.20
13-PWM9: J10.32, U28.20
13-PWM10: J11.32, U31.20
13-PWM11: J12.32, U34.20
13-PWM12: J13.32, U37.20
13-PWM13: J14.32, U40.20
13-PWM14: J15.32, U43.20
13-PWM15: J16.32, U46.20
14: C101.2, U16.5
14-D0: J1.10, U2.17
14-D1: J2.10, U3.17
14-D2: J3.10, U7.17
14-D3: J4.10, U10.17
14-D4: J5.10, U13.17
14-D5: J6.10, U16.17
14-D6: J7.10, U19.17
14-D7: J8.10, U22.17
14-D8: J9.10, U25.17
14-D9: J10.10, U28.17
14-D10: J11.10, U31.17
14-D11: J12.10, U34.17
14-D12: J13.10, U37.17
14-D13: J14.10, U40.17
14-D14: J15.10, U43.17
14-D15: J16.10, U46.17
15: C101.1, U16.6
15-G0: J1.40, U2.21
15-G1: J2.40, U3.21
15-G2: J3.40, U7.21
15-G3: J4.40, U10.21
15-G4: J5.40, U13.21
15-G5: J6.40, U16.21
15-G6: J7.40, U19.21
15-G7: J8.40, U22.21
15-G8: J9.40, U25.21
15-G9: J10.40, U28.21
15-G10: J11.40, U31.21
15-G11: J12.40, U34.21
15-G12: J13.40, U37.21
15-G13: J14.40, U40.21
15-G14: J15.40, U43.21
15-G15: J16.40, U46.21
16: C124.1, U19.7
16-G4/RX1/AUD_IN: J1.19, J1.48, J1.54, U2.25
16-G4/RX1/AUD_IN1: J2.19, J2.48, J2.54, U3.25
16-G4/RX1/AUD_IN2: J3.19, J3.48, J3.54, U7.25
16-G4/RX1/AUD_IN3: J4.19, J4.48, J4.54, U10.25
16-G4/RX1/AUD_IN4: J5.19, J5.48, J5.54, U13.25
16-G4/RX1/AUD_IN5: J6.19, J6.48, J6.54, U16.25
16-G4/RX1/AUD_IN6: J7.19, J7.48, J7.54, U19.25
16-G4/RX1/AUD_IN7: J8.19, J8.48, J8.54, U22.25
16-G4/RX1/AUD_IN8: J9.19, J9.48, J9.54, U25.25
16-G4/RX1/AUD_IN9: J10.19, J10.48, J10.54, U28.25
16-G4/RX1/AUD_IN10: J11.19, J11.48, J11.54, U31.25
16-G4/RX1/AUD_IN11: J12.19, J12.48, J12.54, U34.25
16-G4/RX1/AUD_IN12: J13.19, J13.48, J13.54, U37.25
16-G4/RX1/AUD_IN13: J14.19, J14.48, J14.54, U40.25
16-G4/RX1/AUD_IN14: J15.19, J15.48, J15.54, U43.25
16-G4/RX1/AUD_IN15: J16.19, J16.48, J16.54, U46.25
17: C121.2, U19.5
17-G3/TX1/AUD_OUT: J1.17, J1.46, J1.56, U2.27
17-G3/TX1/AUD_OUT1: J2.17, J2.46, J2.56, U3.27
17-G3/TX1/AUD_OUT2: J3.17, J3.46, J3.56, U7.27
17-G3/TX1/AUD_OUT3: J4.17, J4.46, J4.56, U10.27
17-G3/TX1/AUD_OUT4: J5.17, J5.46, J5.56, U13.27
17-G3/TX1/AUD_OUT5: J6.17, J6.46, J6.56, U16.27
17-G3/TX1/AUD_OUT6: J7.17, J7.46, J7.56, U19.27
17-G3/TX1/AUD_OUT7: J8.17, J8.46, J8.56, U22.27
17-G3/TX1/AUD_OUT8: J9.17, J9.46, J9.56, U25.27
17-G3/TX1/AUD_OUT9: J10.17, J10.46, J10.56, U28.27
17-G3/TX1/AUD_OUT10: J11.17, J11.46, J11.56, U31.27
17-G3/TX1/AUD_OUT11: J12.17, J12.46, J12.56, U34.27
17-G3/TX1/AUD_OUT12: J13.17, J13.46, J13.56, U37.27
17-G3/TX1/AUD_OUT13: J14.17, J14.46, J14.56, U40.27
17-G3/TX1/AUD_OUT14: J15.17, J15.46, J15.56, U43.27
17-G3/TX1/AUD_OUT15: J16.17, J16.46, J16.56, U46.27
18: C121.1, U19.6
18-SCK: J1.57, U2.35
18-SCK1: J2.57, U3.35
18-SCK2: J3.57, U7.35
18-SCK3: J4.57, U10.35
18-SCK4: J5.57, U13.35
18-SCK5: J6.57, U16.35
18-SCK6: J7.57, U19.35
18-SCK7: J8.57, U22.35
18-SCK8: J9.57, U25.35
18-SCK9: J10.57, U28.35
18-SCK10: J11.57, U31.35
18-SCK11: J12.57, U34.35
18-SCK12: J13.57, U37.35
18-SCK13: J14.57, U40.35
18-SCK14: J15.57, U43.35
18-SCK15: J16.57, U46.35
19: C144.1, U22.7
19-CIPO: J1.61, U2.38
19-CIPO1: J2.61, U3.38
19-CIPO2: J3.61, U7.38
19-CIPO3: J4.61, U10.38
19-CIPO4: J5.61, U13.38
19-CIPO5: J6.61, U16.38
19-CIPO6: J7.61, U19.38
19-CIPO7: J8.61, U22.38
19-CIPO8: J9.61, U25.38
19-CIPO9: J10.61, U28.38
19-CIPO10: J11.61, U31.38
19-CIPO11: J12.61, U34.38
19-CIPO12: J13.61, U37.38
19-CIPO13: J14.61, U40.38
19-CIPO14: J15.61, U43.38
19-CIPO15: J16.61, U46.38
20: C141.2, U22.5
21: C141.1, U22.6
21-SDA: J1.12, U2.42
21-SDA1: J2.12, U3.42
21-SDA2: J3.12, U7.42
21-SDA3: J4.12, U10.42
21-SDA4: J5.12, U13.42
21-SDA5: J6.12, U16.42
21-SDA6: J7.12, U19.42
21-SDA7: J8.12, U22.42
21-SDA8: J9.12, U25.42
21-SDA9: J10.12, U28.42
21-SDA10: J11.12, U31.42
21-SDA11: J12.12, U34.42
21-SDA12: J13.12, U37.42
21-SDA13: J14.12, U40.42
21-SDA14: J15.12, U43.42
21-SDA15: J16.12, U46.42
22: C164.1, U25.7
22-SCL: J1.14, U2.39
22-SCL1: J2.14, U3.39
22-SCL2: J3.14, U7.39
22-SCL3: J4.14, U10.39
22-SCL4: J5.14, U13.39
22-SCL5: J6.14, U16.39
22-SCL6: J7.14, U19.39
22-SCL7: J8.14, U22.39
22-SCL8: J9.14, U25.39
22-SCL9: J10.14, U28.39
22-SCL10: J11.14, U31.39
22-SCL11: J12.14, U34.39
22-SCL12: J13.14, U37.39
22-SCL13: J14.14, U40.39
22-SCL14: J15.14, U43.39
22-SCL15: J16.14, U46.39
23: C161.2, U25.5
23-COPI: J1.59, U2.36
23-COPI1: J2.59, U3.36
23-COPI2: J3.59, U7.36
23-COPI3: J4.59, U10.36
23-COPI4: J5.59, U13.36
23-COPI5: J6.59, U16.36
23-COPI6: J7.59, U19.36
23-COPI7: J8.59, U22.36
23-COPI8: J9.59, U25.36
23-COPI9: J10.59, U28.36
23-COPI10: J11.59, U31.36
23-COPI11: J12.59, U34.36
23-COPI12: J13.59, U37.36
23-COPI13: J14.59, U40.36
23-COPI14: J15.59, U43.36
23-COPI15: J16.59, U46.36
24: C161.1, U25.6
25: C184.1, U28.7
25-G1/AUD_LRCLK/SCL1: J1.42, J1.52, J1.53, U2.14
25-G1/AUD_LRCLK/SCL2: J2.42, J2.52, J2.53, U3.14
25-G1/AUD_LRCLK/SCL3: J3.42, J3.52, J3.53, U7.14
25-G1/AUD_LRCLK/SCL4: J4.42, J4.52, J4.53, U10.14
25-G1/AUD_LRCLK/SCL5: J5.42, J5.52, J5.53, U13.14
25-G1/AUD_LRCLK/SCL6: J6.42, J6.52, J6.53, U16.14
25-G1/AUD_LRCLK/SCL7: J7.42, J7.52, J7.53, U19.14
25-G1/AUD_LRCLK/SCL8: J8.42, J8.52, J8.53, U22.14
25-G1/AUD_LRCLK/SCL9: J9.42, J9.52, J9.53, U25.14
25-G1/AUD_LRCLK/SCL10: J10.42, J10.52, J10.53, U28.14
25-G1/AUD_LRCLK/SCL11: J11.42, J11.52, J11.53, U31.14
25-G1/AUD_LRCLK/SCL12: J12.42, J12.52, J12.53, U34.14
25-G1/AUD_LRCLK/SCL13: J13.42, J13.52, J13.53, U37.14
25-G1/AUD_LRCLK/SCL14: J14.42, J14.52, J14.53, U40.14
25-G1/AUD_LRCLK/SCL15: J15.42, J15.52, J15.53, U43.14
25-G1/AUD_LRCLK/SCL16: J16.42, J16.52, J16.53, U46.14
26: C181.2, U28.5
26-G2/AUD_BCLK/SDA1: J1.44, J1.50, J1.51, U2.15
26-G2/AUD_BCLK/SDA2: J2.44, J2.50, J2.51, U3.15
26-G2/AUD_BCLK/SDA3: J3.44, J3.50, J3.51, U7.15
26-G2/AUD_BCLK/SDA4: J4.44, J4.50, J4.51, U10.15
26-G2/AUD_BCLK/SDA5: J5.44, J5.50, J5.51, U13.15
26-G2/AUD_BCLK/SDA6: J6.44, J6.50, J6.51, U16.15
26-G2/AUD_BCLK/SDA7: J7.44, J7.50, J7.51, U19.15
26-G2/AUD_BCLK/SDA8: J8.44, J8.50, J8.51, U22.15
26-G2/AUD_BCLK/SDA9: J9.44, J9.50, J9.51, U25.15
26-G2/AUD_BCLK/SDA10: J10.44, J10.50, J10.51, U28.15
26-G2/AUD_BCLK/SDA11: J11.44, J11.50, J11.51, U31.15
26-G2/AUD_BCLK/SDA12: J12.44, J12.50, J12.51, U34.15
26-G2/AUD_BCLK/SDA13: J13.44, J13.50, J13.51, U37.15
26-G2/AUD_BCLK/SDA14: J14.44, J14.50, J14.51, U40.15
26-G2/AUD_BCLK/SDA15: J15.44, J15.50, J15.51, U43.15
26-G2/AUD_BCLK/SDA16: J16.44, J16.50, J16.51, U46.15
27: C181.1, U28.6
27-D1: J1.18, U2.16
27-D2: J2.18, U3.16
27-D3: J3.18, U7.16
27-D4: J4.18, U10.16
27-D5: J5.18, U13.16
27-D6: J6.18, U16.16
27-D7: J7.18, U19.16
27-D8: J8.18, U22.16
27-D9: J9.18, U25.16
27-D10: J10.18, U28.16
27-D11: J11.18, U31.16
27-D12: J12.18, U34.16
27-D13: J13.18, U37.16
27-D14: J14.18, U40.16
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

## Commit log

2020-05-14 intial commit
    [SparkFun_MicroMod_ESP32.brd, SparkFun_MicroMod_ESP32.sch]
2020-05-15 updated Prod_IDs
    Added missing PROD_IDs
    Added Logos to sch
    [SparkFun_MicroMod_ESP32.brd, SparkFun_MicroMod_ESP32.sch]
2020-05-21 Updated design
    [SparkFun_MicroMod_ESP32.brd, SparkFun_MicroMod_ESP32.sch]
2020-05-21 Fixed RF trace Width
    - Updated RF trace width to 13mil, added calculation to schematic
    [SparkFun_MicroMod_ESP32.brd, SparkFun_MicroMod_ESP32.sch]
2020-05-26 v01 silk update
    rotated the silk to line up with carrier boards
    [SparkFun_MicroMod_ESP32.brd, SparkFun_MicroMod_ESP32.sch]
2020-06-22 v02
    - Replaced antenna inductor with 0 ohm resistor
    - Replaced Flash IC VDD supply from 3.3V power rail to ESP32's FLASH_VDD pin.
    - Replaced edge connector to updated pinout
    [SparkFun_MicroMod_ESP32.brd, SparkFun_MicroMod_ESP32.sch]
2020-06-22 v02 updated top copper
    [SparkFun_MicroMod_ESP32.brd]
2020-07-29 v10
    - Updated board to v10
    - Removed RX and TX test points
    - Changed Flash_VDD label to VDD power symbol
    - Changed SPI labels to COPI CIPO
    - Added vias below antenna
    - Moved OSHW logo
    [SparkFun_MicroMod_ESP32.brd, SparkFun_MicroMod_ESP32.sch]
2020-07-31 Production Files
    [SparkFun_MicroMod_ESP32-Panel.GBL, SparkFun_MicroMod_ESP32-Panel.GBO, SparkFun_MicroMod_ESP32-Panel.GBP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]
2020-08-17 v10 fix
    Rearranged GPIO pins
    -Boot was removed from I2C_INT
    -GPIO4 was moved from G0 to I2C_INT
    -GPIO12 was moved from G1 to G4
    -Moved GPIO25/26 from G4/5 to G0/1
    -Swapped GPIO16/17 from G2/3 to G3/2
    [SparkFun_MicroMod_ESP32.brd, SparkFun_MicroMod_ESP32.sch]
2020-08-17 New panel
    [SparkFun_MicroMod_ESP32-Panel.brd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]
2020-08-31 Updated MicroMod Connector Schematic Symbol
    [SparkFun_MicroMod_ESP32.sch]
2020-09-08 Updated USB to UART
    USB to UART converter can be either the CP2102N or CP2104
    [SparkFun_MicroMod_ESP32.brd, SparkFun_MicroMod_ESP32.sch]
2020-09-17 v11
    - Updated to new MicroMod Pinout
    - Changed SCK from 14 to 18
    - Changed SDO from 15 to 23
    - Changed SDI from 2 to 19
    - Changed CS from 13 to 5
    - Changed PWM0 from 18 to 13
    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
    [SparkFun_MicroMod_ESP32.brd, SparkFun_MicroMod_ESP32.sch]
2020-09-18 v11 update
    - Added notes to boot strapping pins
    - Added ENIG finish note to tDocu
    - Updated labeling for USB to UART brdige
    - Updated SPI flash labels
    [SparkFun_MicroMod_ESP32.brd, SparkFun_MicroMod_ESP32.sch]
2020-09-21 v11 updated inner layers
    [SparkFun_MicroMod_ESP32.brd]
2020-09-21 v11 Panel
    [SparkFun_MicroMod_ESP32-Panel.brd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]

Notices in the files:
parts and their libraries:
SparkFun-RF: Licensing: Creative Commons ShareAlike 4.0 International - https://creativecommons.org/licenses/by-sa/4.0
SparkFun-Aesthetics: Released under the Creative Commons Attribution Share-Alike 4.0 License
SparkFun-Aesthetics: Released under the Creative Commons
